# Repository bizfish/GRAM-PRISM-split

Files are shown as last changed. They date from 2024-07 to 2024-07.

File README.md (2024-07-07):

# GRAM PRI$M - SPLIT PARTS

https://github.com/bizfish/GRAM-PRISM-split/assets/41658201/d22e8284-e495-4ec5-a12b-59414b27cd8d

# Introduction 
The **PRI$M** is a modular take on the Prism, originally designed by WunWae. It has the standard pinout for firmwares like HayBox and Pico-Rectangle, and is also compatible with more fleshed-out FGC firmwares like GP2040-CE. The key distinctive features between the original Prism and the PRI$M is the USB-C connectivity, and the modular panels that can be replaced and swapped to change the hand layouts without purchasing a whole new controller. With industrial design from GRAM, PCB designed by Quark.Works, this guide goes over a DIY-friendly approach to building and modifying the PRI$M to suit your needs.

This fork splits the frame into panels which can be FDM printed parallel to the build plate to reduce support use and allow split colors with multi-material printing.

**If you would like to support the original developers of this project, consider purchasing parts like buttons, PCBs, USB-C to GCC cables, and official GRAM builds at [GRAMCTRL.COM](https://www.gramctrl.com) rather than a fab house.**



Included Files
-
Included in this repo is all the files needed to get started with a PRI$M build:
- **Split PRI$M Frame .stl files**
- **Bambu Labs .3mf file with split color frame parts**
- **Aluminum Panel** Gerber files in a new split color design *(5 of 'em!)*
- **PCB Gerbers** for multiple hand layouts and a panelized version for the standard layout

Additional Information
-
If you want more info around GRAM builds, both open source and official builds, please join the [GRAM Digital Controllers Discord](https://discord.gg/6TuHw2r2X4) to ask questions and work with the community! I would love to see people creating new interesting designs, and building upon our initial framework.

Thanks & Acknowledgements
-
There are several people who made this project possible, either directly or indirectly.
- [Quark](https://twitter.com/quark_works), who did the PCB design on this and many other GRAM projects.
- [WunWae](https://twitter.com/WuhnWae), who developed the ergonomics and original Prism design. Thank you for your blessing on this crazy project!
- [Grammy](https://twitter.com/grammy_money), who developed the GRAM PRI$M
- Grammmy's life and business partner [BRUISES](https://twitter.com/bruisesxo), who has turned GRAM into what it is today, and had incredible patience with Grammy as they toiled away at their computer late into the night designing this thing.

# Ordering & Customization Guide
While most of these files are universal and can be used at any fab house, **JLCPCB** has become the de-facto standard for DIY box manufacturing. This is due to their hyper-affordable pricing and low minimum order quantity.

Bill of Materials
-
Per GRAM PRI$M, you will need (some files can be made using this repository, but I will link to places to purchase them if you would like to avoid MOQs)
- 1 x PRI$M PCB set *(either panelized, or individual PCBs)*
- 1 x set of PRI$M Aluminum Panels
- 20 x [Kailh Choc V1 switches](https://www.moergo.com/products/kailh-choc-v1-key-switches-red-brown-white-pro-red-20-pack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) (Red, Red Pro, and Whites are all great choices)
- 20 x [PG1350 Hotswap Sockets](https://mkultra.click/kailh-hotswap-sockets)
- 20 x Choc v1 keycaps *(I recommend MBK profile)*
- 1 x set of GRAM PRI$M Frame parts
- 8 x [M5x0.8 10mm Low-Profile Socket Head Screws](https://www.amazon.com/dp/B0CJ6P4F9Q)
- 2 x M2 6mm bolts
- 12 x M3x0.5 8mm bolts
- 1 x [4" JST 6-pin Socket to Socket Reversed cable assembly](https://www.digikey.com/en/products/detail/jst-sales-america-inc/A06SR06SR30K102A/9922193)
- 1 x [4" 14-pin FPC Cable](https://www.digikey.com/en/products/detail/molex/0152670295/4427171)

*Optional*
- USB-C to GCC cable for console/adapter play

Tools Needed
-This guide assumes a level of knowledge on soldering and computer literacy. General tool requirements are:
  - Soldering iron
  - Solder
  - USB-C to USB-A cable
  - allen wrenches as needed
  - Pliers
  - Patience :)

The PCB
-
***Note: Since the ordering process of the PRI$M is almost identical to the [SLIM](https://github.com/GrammyMoney/GRAM-SLIM), I have used the ordering guide from the SLIM here. You may need to do more repetitions of these steps depending on which PCB you are printing, and you need to do the panel steps for all 5 aluminum panels.***

The PCB Fabrication files should come in the form of a *Gerber ZIP file* and *bom/cpl files* (usually in Excel spreadsheet formats).

Drag them into the "Upload Gerbers" box at JLCPCB and this page will pop up:



Here you can change the color of the PCB. Green is the fastest and cheapest from JLC, but their black PCBs look *siiiiiick*. The only setting I recommend you change is to check "**Yes**" on *Confirm Production file*. This allows for any mistakes to be ironed out by their engineers.

**If you're using the panelized design, under "Different Design" select 3 or they'll reach out to you about your mistake and charge you the difference.**

Towards the bottom of the page, you want to turn on the switch for **PCB ASSEMBLY**.



Make sure you are assembling the *Bottom Side* of the PCB, and make sure to set *Confirm Parts Placement* to "**Yes**". None of the advanced options need to be changed.

Upon confirming your PCB Assembly options, you'll be taken to the Assembly wizard. Clicking next will give you a location to upload the *BOM* and *CPL* files (*CPL* is referred to as *Positions* in the GRAM Slim files). Once you click through, you'll be brought to you BOM list.



This will allow you to modify parts if there's any low stock. There's a line at the bottom for CH1-CH21 with some red text. This is for assembling hotswap sockets, which is not recommended for JLC, as you have to preorder them. when you click **next**, continue by clicking *Do not place*.



The wizard looks intimidating, but good news! Since you're confirming part placement, the JLC engineers will fix any errors. Just go ahead and continue.

There you have it! Your PCB is ready to order.

The Panels
-
The process of ordering aluminum panels from JLC is similar to the PCB ordering process, but much simpler. Start by dragging the **GRAM Slim Top** Zip file into the JLC upload window. We want an aluminum PCB, 1.6mm. You can choose either white or black coating (white tends to be glossy, black is matte but a fingerprint magnet). 



Under High-spec Options, make sure to remove order number, or else they'll put an ugly serial number on the panel.

Once you save to cart, you'll see this screen:



Here you can add the **GRAM Slim Bottom** Zip file, and it will copy all your settings from the Top panel. Save to cart, and you're ready to check out with your PCBs!

The Frame
-
The frame files are straightforward - print them yourself using material you're comfortable with. The 3mf file has all parts arranged for Bambu Labs A1 with muti-material printing set up for the split look, with the settings I've been using. You can always change the two filaments to be the same in the slicer if you don't have/want to use multi-material printing.

Need help building your PRI$M? Feel free to join our [Discord](https://discord.gg/gramctrl) for advice from our lovely open source community!

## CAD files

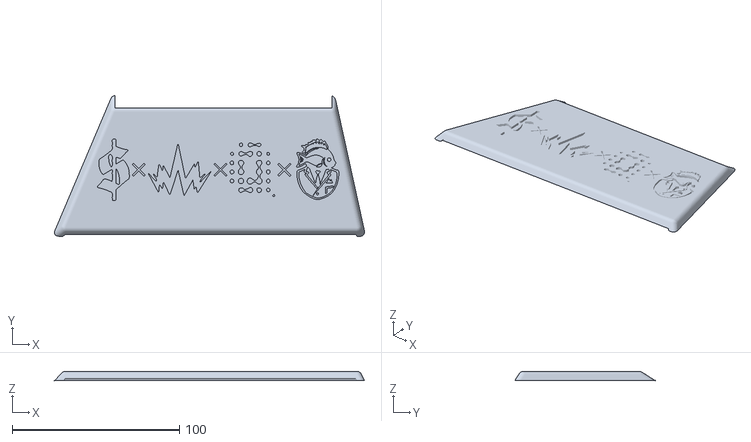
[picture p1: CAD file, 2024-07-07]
v1/GRAM Production Files/gram prism v1 lower back.stl
185.1 x 84.0 x 5.60

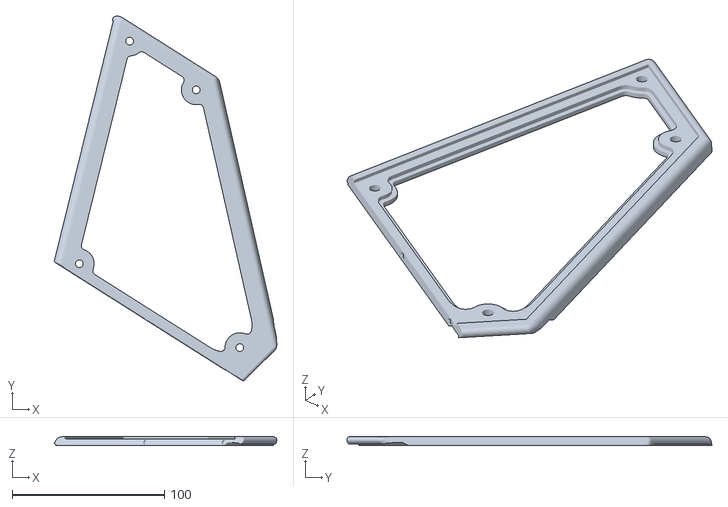
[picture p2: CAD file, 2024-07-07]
v1/GRAM Production Files/gram prism v1 left hand panel.stl
146.5 x 240.1 x 5.60

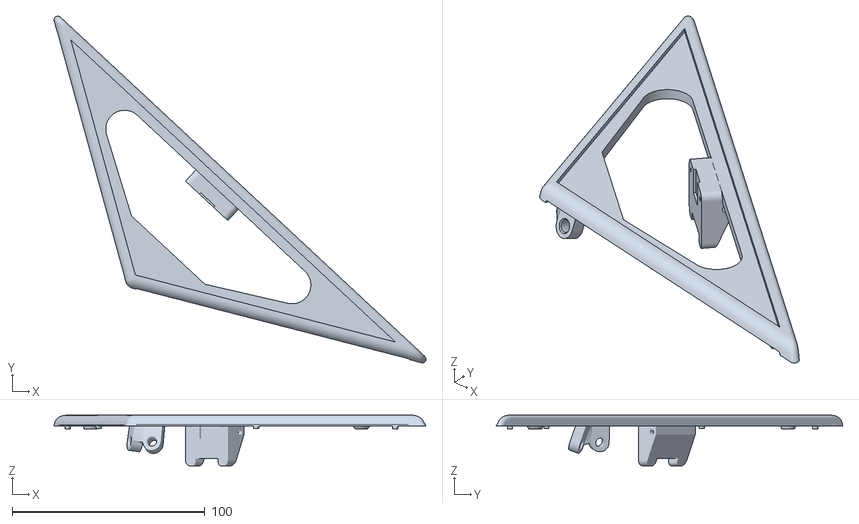
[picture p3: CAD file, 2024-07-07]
v1/GRAM Production Files/gram prism v1 front.stl
192.8 x 179.7 x 26.3

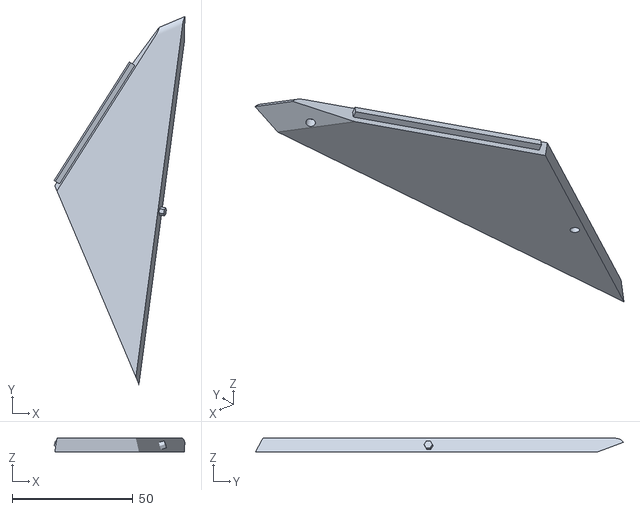
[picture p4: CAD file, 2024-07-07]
v1/GRAM Production Files/gram prism v1 back right.stl
54.1 x 152.2 x 5.60

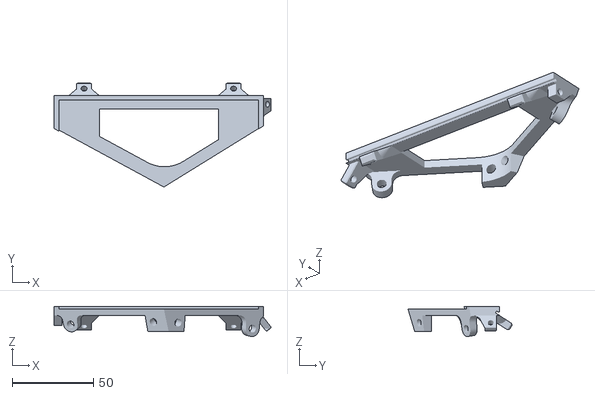
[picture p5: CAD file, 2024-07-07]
v1/GRAM Production Files/gram prism v1 smallest back.stl
133.6 x 64.1 x 18.6

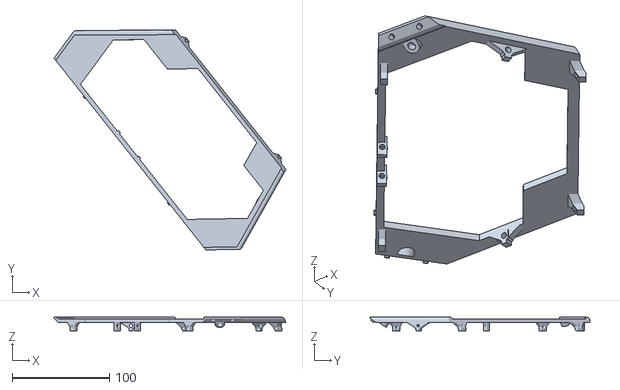
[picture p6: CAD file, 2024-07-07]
v1/GRAM Production Files/gram prism v1 bottom.stl
238.5 x 226.0 x 13.9

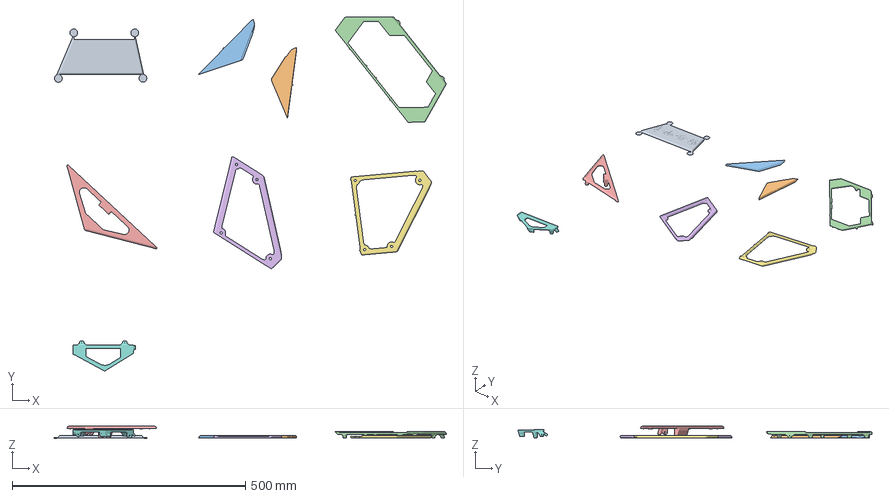
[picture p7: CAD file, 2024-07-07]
v1/GRAM Production Files/gram prism v1 split multicolor.3mf
840.4 x 759.5 x 26.3 mm
Assembly x 3
Back Right (1)
Back Left (1)
Left Hand Panel (1) (1)
Right Hand Panel (1) (1)
Smallest Back (1) (1)

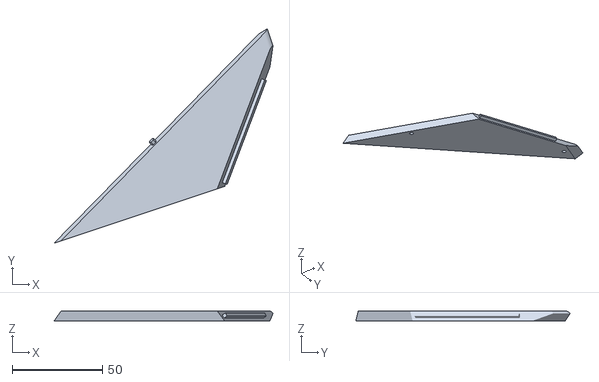
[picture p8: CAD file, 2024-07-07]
v1/GRAM Production Files/gram prism v1 back left.stl
121.1 x 118.6 x 5.60

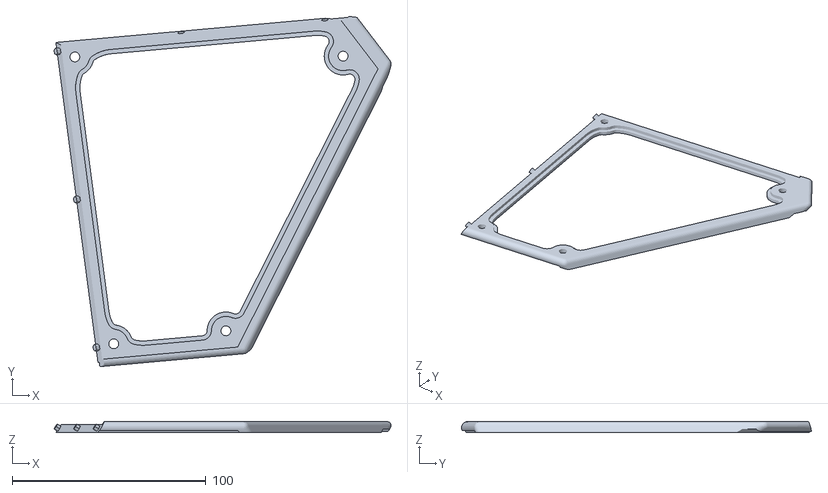
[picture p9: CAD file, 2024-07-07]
v1/GRAM Production Files/gram prism v1 right hand panel.stl
174.0 x 180.8 x 5.60
